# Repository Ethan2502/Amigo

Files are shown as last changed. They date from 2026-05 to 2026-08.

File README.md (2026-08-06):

# Amigo

A desk companion cube that takes over the things you unlock your phone for, so you have no reason to pick it up.

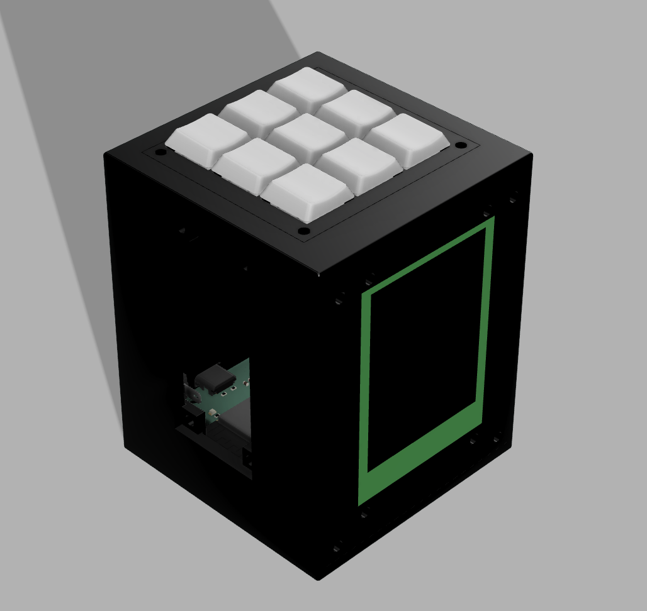
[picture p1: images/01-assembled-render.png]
Amigo assembled


## Why I made it

This is my project that I got an idea for when my phone's alarm went off. I always tend to use my phone a little bit in bed when I wake up. I thought I needed my phone to wake me up but then I thought of a product that replaced all the "utility" items your phone could do but without the distractions. I used screentime apps before but they always make it in fingers reach to disable it. Amigo takes the other approach. Instead of locking the phone down, it takes over the jobs you unlock the phone for in the first place, so there is nothing to reach for.

Physically locking the phone away is something I want to add later. The current design does not do it.

## What it does

1. **Wakes you up.** Alarm clock, so your phone doesn't have to be the thing next to your bed.
2. **Keeps your phone down.** The alarm, timer, and display all live on the cube, so there is no reason to unlock your phone for any of them.
3. **Utility stuff.** Timers, stopwatch, and the other simple things you'd normally pull your phone out for.
4. **Desk toy.** Displays pictures on a slide deck while you work.
5. **Classroom toy.** Small kids in elementary school can use it to develop cognitive function with memory games or reaction time tests. It can teach them things through games where they answer questions using the keypad as arrows or other controls to move, fight, and so on. It's a lot cheaper than buying a brand new computer or phone, so it's a budget friendly classroom toy.

## How it works

Amigo is two PCBs and a 3D printed case.

The **main board** carries an ESP32-S3-WROOM-1, a TP4056 LiPo charger, an AP2112K 3.3 V LDO, and headers for the display, the audio amp, the power switch, and the button matrix. It runs off a single-cell LiPo and charges over USB-C.

The **3x3 button matrix board** is a separate PCB with nine Kailh Choc hotswap switches and nine 1N4148W diodes in a standard row/column matrix, so nine keys read over six GPIO. It connects to the main board through an 8-pin ribbon header.

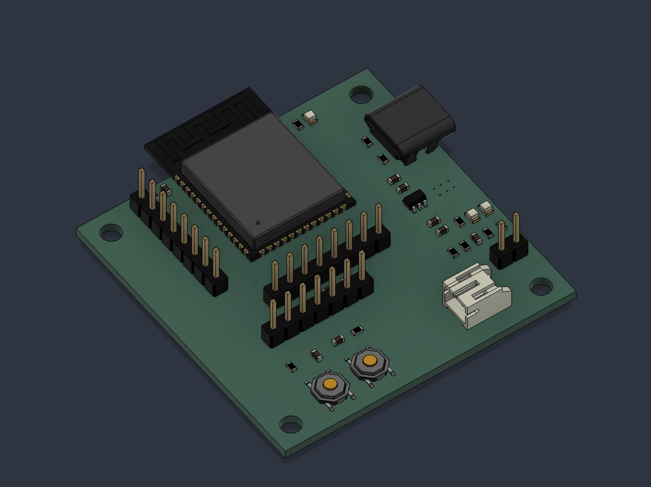
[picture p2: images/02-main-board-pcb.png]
Main board PCB render


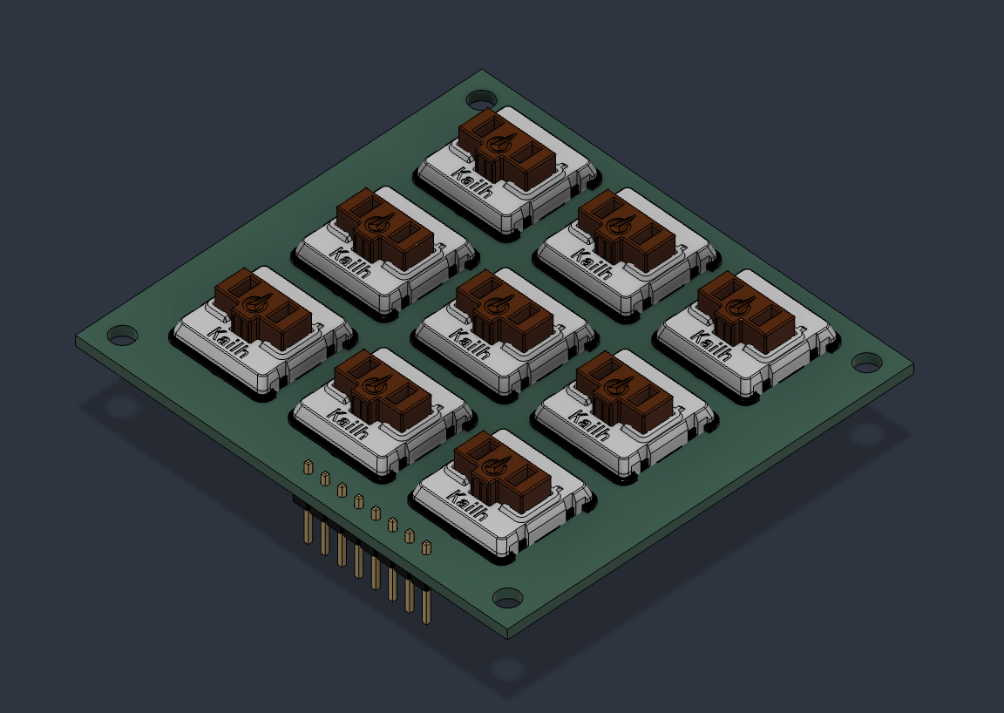
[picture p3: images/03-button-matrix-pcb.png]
Button matrix PCB render


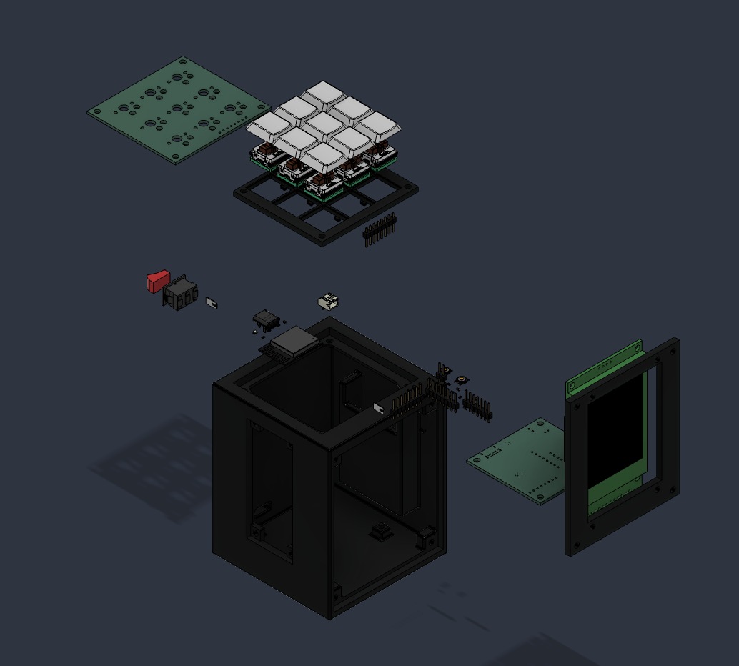
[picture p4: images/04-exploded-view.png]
Exploded View


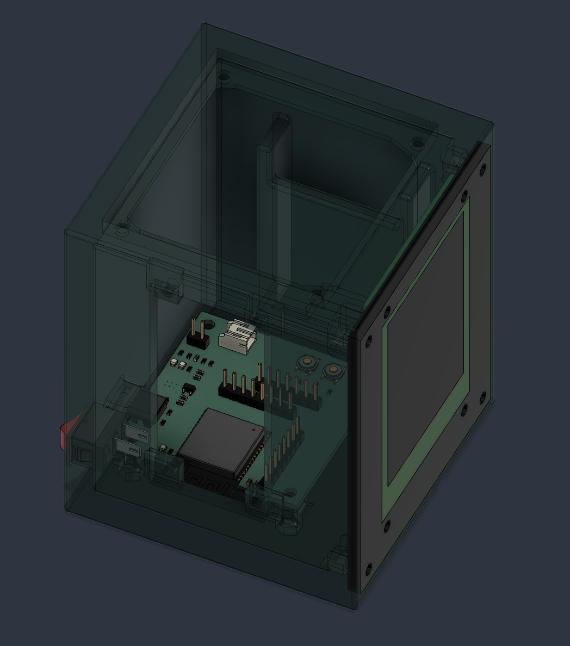
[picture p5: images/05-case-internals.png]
Case Internals


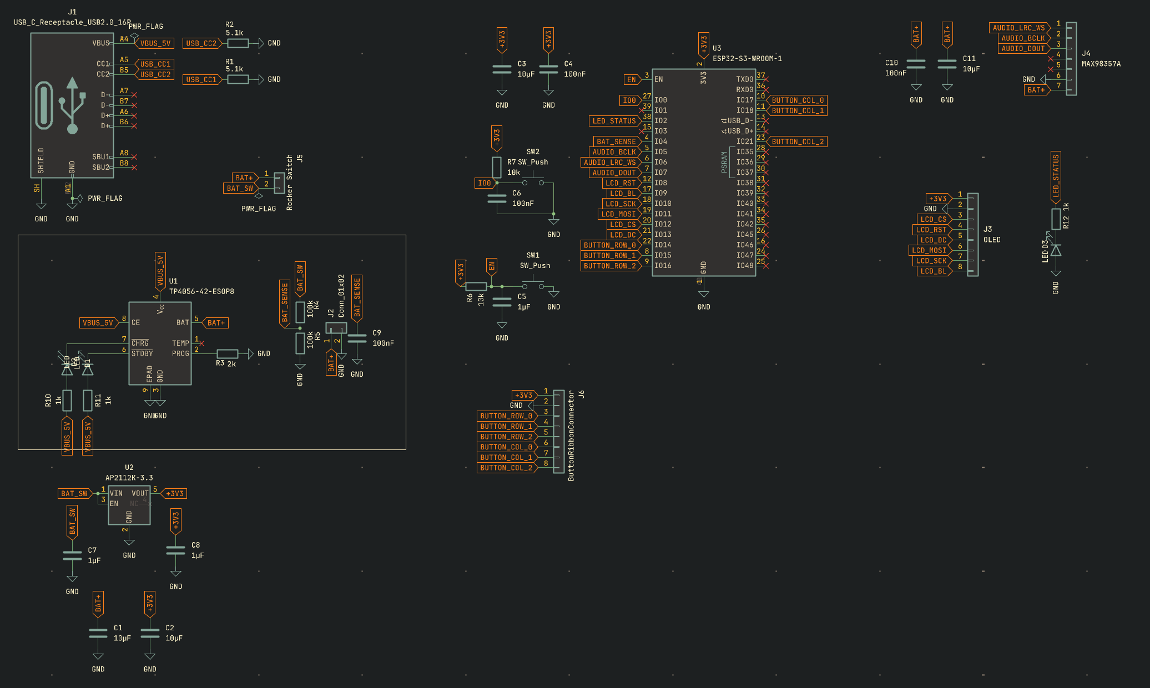
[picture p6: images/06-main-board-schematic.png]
Main Schematic


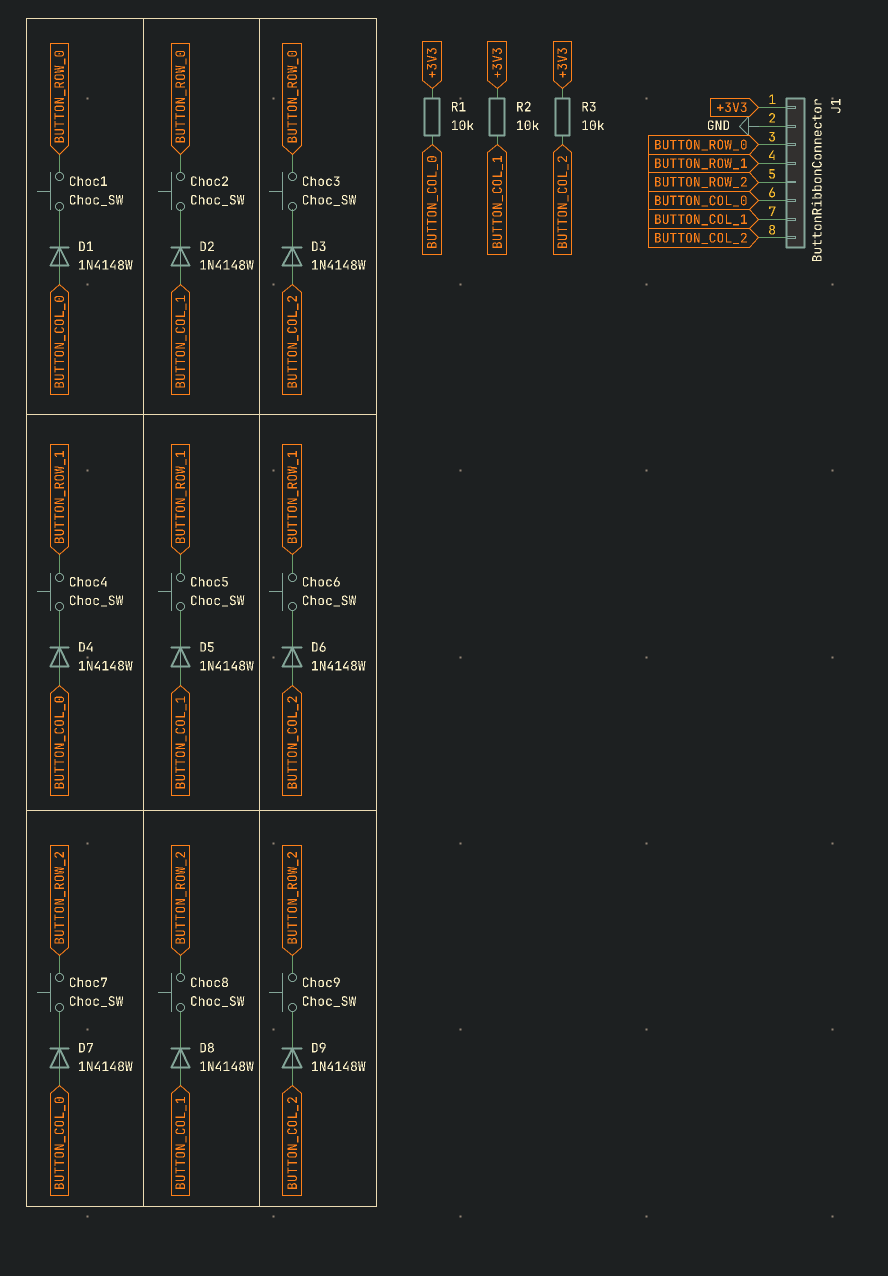
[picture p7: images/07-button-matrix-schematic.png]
Buttons Schematic


## Repo layout

```
hardware/
  main-board/          KiCad project for the ESP32-S3 main board
    production/        gerbers, BOM, pick-and-place files
  button-matrix/       KiCad project for the 3x3 switch board
    libs/              Keebio-Parts footprint library (third party, see credits)
    production/
cad/
  amigo.f3z            Fusion 360 Archive file for multi-component assemblies
  step/                STEP exports
  stl/                 printable parts
docs/                  assembly instructions
firmware/              (in progress)
images/                renders and photos
bom.csv                full bill of materials
```

## Assembly

### 1. Order the PCBs

Send `hardware/main-board/production/gerbers.zip` and `hardware/button-matrix/production/gerbers.zip` to your fab house. Both are 2-layer, 1.6 mm.

You can use PCBA to save time on soldering. If you don't it will be harder and you may or may not have to make a stencil. I ordered PCBA

### 2. Print the case

| Part | File | Notes |
| --- | --- | --- |
| Case | `cad/stl/case.stl` | Needs supports |
| Button cover | `cad/stl/button-cover.stl` | 10% Gyroid |
| Display mount | `cad/stl/display-mount.stl` | 10% Gyroid |
| Keycaps | `cad/stl/keycaps.stl` | x9 10% Gyroid |

Settings I used:
1. Gyroid Infill at 10%
2. Supports only on the case
3. The rest I used bambu slicer and their default settings for PLA

### 3. Solder the main board

If you ordered PCBA then skip. 

Use solder paste, wick, and flux to do solder. I believe using a stencil will make applying solder paste easier but I ordered PCBA. Solder all the parts on to it and also
don’t forget things like key caps for the buttons. Refer to Ki Cad files as
instructions for each cap or resistor and anything else you may need. 

Also the ESP board and the TP4056 should probably be soldered first because they are the most finicky. The TP4056 also has a thermal pad underneath. I suggest soldering all the passives like capacitators and resistors last.

### 4. Solder the button matrix

When you solder the button matrix it is important to make sure your diodes are the right direction. Normally when assmbling things I find it easier to have the file open whether it be a CAD or a PCB design. This way it is concrete in exactly what direction you planned for it earlier. Also don't forget keycaps while soldering.

### 5. Wire the modules

Again you can pull up the file to see which way the order is for the pin connectors. You can then work through it wire by wire by counting. This is the most concrete way to do it withought messing up. To be extra secure you can use some hot glue and secure the connection. 

### 6. Assemble the Cube

Use M3 screws and nuts to screw everything in. There should be a hole for each screw.

### 7. Flash the Firmware

Once firmware is written you can flash it. I have not written it yet I will update it later.

## Bill of Materials

Prices are per-unit at the quantity needed to build one Amigo. Several LCSC parts have minimum order quantities well above what the board uses (the 0603 passives ship in reels of 50 or 100), so the actual amount you spend at checkout will be higher than the totals below.

The main board was ordered as PCBA, so the surface-mount parts in the first table were supplied to the assembler rather than hand-soldered. The button matrix board was ordered bare and assembled by hand.

### Main board

| Ref | Part | Qty | Unit | Total | Link |
| --- | --- | --- | --- | --- | --- |
| U3 | ESP32-S3-WROOM-1-N16R8 | 1 | $5.16 | $5.16 | [C2913202](https://www.lcsc.com/product-detail/C2913202.html) |
| U1 | TP4056-42-ESOP8 LiPo charger (ESOP-8) | 1 | $0.19 | $0.19 | [C16581](https://www.lcsc.com/product-detail/C16581.html) |
| U2 | AP2112K-3.3TRG1 LDO (SOT-23-5) | 1 | $0.11 | $0.11 | [C23380830](https://www.lcsc.com/product-detail/C23380830.html) |
| J1 | USB4085-GF-A USB-C receptacle | 1 | $1.42 | $1.42 | [C7095263](https://www.lcsc.com/product-detail/C7095263.html) |
| J2 | S2B-PH-K-S-GW JST PH 2-pin, right angle | 1 | $0.18 | $0.18 | [C157932](https://www.lcsc.com/product-detail/C157932.html) |
| J3 | PPTC081LFBN-RC female header 1x08 2.54 mm (display) | 1 | $1.54 | $1.54 | [C3320851](https://www.lcsc.com/product-detail/C3320851.html) |
| J4 | PPTC071LFBN-RC female header 1x07 2.54 mm (audio amp) | 1 | $0.79 | $0.79 | [C5342086](https://www.lcsc.com/product-detail/C5342086.html) |
| J5 | PRPC002SAAN-RC pin header 1x02 2.54 mm (power switch) | 1 | $0.09 | $0.09 | [C3346540](https://www.lcsc.com/product-detail/C3346540.html) |
| J6 | PPTC081LFBN-RC female header 1x08 2.54 mm (button ribbon) | 1 | $1.54 | $1.54 | [C3320851](https://www.lcsc.com/product-detail/C3320851.html) |
| SW1, SW2 | TL3342F260QG tactile switch | 2 | $1.15 | $2.29 | [C2886894](https://www.lcsc.com/product-detail/C2886894.html) |
| D1 | YLED0805G green LED, 0805 | 1 | $0.01 | $0.01 | [C25170728](https://www.lcsc.com/product-detail/C25170728.html) |
| D2 | YLED0805B blue LED, 0805 | 1 | $0.01 | $0.01 | [C19273154](https://www.lcsc.com/product-detail/C19273154.html) |
| D3 | YLED0805R red LED, 0805 | 1 | $0.01 | $0.01 | [C19171391](https://www.lcsc.com/product-detail/C19171391.html) |
| C1, C2, C3, C11 | 10 µF 25 V X5R, 0603 | 4 | $0.48 | $1.92 | [C344022](https://www.lcsc.com/product-detail/C344022.html) |
| C4, C6, C9, C10 | 100 nF 50 V X7R, 0603 | 4 | $0.02 | $0.08 | [C14663](https://www.lcsc.com/product-detail/C14663.html) |
| C5, C7, C8 | 1 µF 25 V X7R, 0603 | 3 | $0.02 | $0.07 | [C29936](https://www.lcsc.com/product-detail/C29936.html) |
| R1, R2 | 5.1 kΩ 1%, 0603 | 2 | $0.01 | $0.01 | [C105580](https://www.lcsc.com/product-detail/C105580.html) |
| R3 | 2 kΩ 5%, 0603 | 1 | $0.01 | $0.01 | [C105581](https://www.lcsc.com/product-detail/C105581.html) |
| R4, R5 | 100 kΩ 1%, 0603 | 2 | $0.01 | $0.01 | [C14675](https://www.lcsc.com/product-detail/C14675.html) |
| R6, R7 | 10 kΩ 1%, 0603 | 2 | $0.01 | $0.01 | [C98220](https://www.lcsc.com/product-detail/C98220.html) |
| R10, R11, R12 | 1 kΩ 1%, 0603 | 3 | $0.01 | $0.02 | [C22548](https://www.lcsc.com/product-detail/C22548.html) |
| | **Main board subtotal** | | | **$15.47** | |

### Button matrix board

| Ref | Part | Qty | Unit | Total | Link |
| --- | --- | --- | --- | --- | --- |
| CHOC1-CHOC9 | Kailh Choc low profile hotswap socket | 9 | $0.78 | $7.02 | [Amazon](https://www.amazon.com/Mechkeeb-Kailh-Low-Hot-swappable-Socket/dp/B0BS3L174L) |
| | Kailh Choc low profile keyswitch | 9 | $1.92 | $17.28 | [Amazon](https://www.amazon.com/KAILH-Official-Chocolate-Mechanical-Keyboard/dp/B0B3MNBPSP) |
| D1-D9 | 1N4148W diode, SOD-123 | 9 | $0.01 | $0.08 | [C908248](https://www.lcsc.com/product-detail/C908248.html) |
| J1 | Header 1x08 2.54 mm (ribbon to main board) | 1 | $1.54 | $1.54 | [C3320851](https://www.lcsc.com/product-detail/C3320851.html) |
| R1, R2, R3 | 10 kΩ 1%, 0603 | 3 | $0.01 | $0.02 | [C98220](https://www.lcsc.com/product-detail/C98220.html) |
| | **Button matrix subtotal** | | | **$25.94** | |

Keycaps are 3D printed from `cad/stl/keycaps.stl`, so there is nothing to buy for them.

### Off-board parts

| Part | Qty | Unit | Total | Link |
| --- | --- | --- | --- | --- |
| HiLetgo 2.8 in ILI9341 SPI display, 240x320 | 1 | $16.39 | $16.39 | [Amazon](https://www.amazon.com/HiLetgo-240X320-Resolution-Display-ILI9341/dp/B073R7BH1B) |
| MAX98357A I2S audio amp breakout | 1 | $6.88 | $6.88 | [Amazon](https://www.amazon.com/MAX98357-MAX98357A-Amplifier-Interface-Raspberry/dp/B0DPJRLMDJ) |
| CQRobot speaker, JST-PH 2.0 mm interface | 1 | $7.99 | $7.99 | [Amazon](https://www.amazon.com/CQRobot-JST-PH2-0-Interface-Electronic-Projects/dp/B0738NLFTG) |
| EEMB 1100 mAh single-cell LiPo, JST connector | 1 | $6.15 | $6.15 | [Amazon](https://www.amazon.com/EEMB-1100mAh-Battery-Rechargeable-Connector/dp/B08VRYS8FT) |
| Rocker power switch | 1 | $1.35 | $1.35 | [AliExpress](https://www.aliexpress.us/item/3256812208202705.html) |
| Jumper wires, board-to-board ribbon link | 1 | $6.98 | $6.98 | [Amazon](https://www.amazon.com/Elegoo-EL-CP-004-Multicolored-Breadboard-arduino/dp/B01EV70C78) |
| PLA filament for case, button cover, display mount, keycaps | 1 | $20.00 | $20.00 | [Polymaker](https://shop.polymaker.com/products/polymaker-pla-pro?variant=41550910652473) |
| M3 screws and nuts pack of 100 | 1 | $15.30 | $15.30 | [McMaster](https://www.mcmaster.com/products/screws/socket-head-screws-2~/steel-socket-head-screws~~/?s=m3+screws) |
| PCB fabrication: main board PCBA and button matrix bare PCB | 1 | $50.65 | $50.65 | [JLCPCB](https://jlcpcb.com/) |
| | | | **$131.69 plus fasteners** | |

The Amazon parts ship in fixed pack sizes rather than the exact count the build uses. The Unit column is the per-item price and the Total is what one Amigo consumes, so your checkout total will be higher.

### Total

**$173.10 plus fasteners** to build one Amigo: $15.47 for the main board, $25.94 for the button matrix, and $116.39 in off-board parts and fabrication. Fabrication is the single largest line at $50.65.

## Tools used

Not part of the build, listed for anyone reproducing it.

| Tool | Link |
| --- | --- |
| Soldering iron | [Amazon](https://www.amazon.com/Wonderway-Soldering-Electronics-CELLPHONE-Repairing/dp/B0BLSJQPR6) |
| Desoldering pump | [Amazon](https://www.amazon.com/Lesnow-Desoldering-Electronics-Disassemble-Electrical/dp/B0F8BJPC9Y) |
| Multimeter | [Amazon](https://www.amazon.com/ANENG-Multimeter-Resistance-Continuity-Automotive/dp/B0BYD32JZV) |

## Firmware

Not written yet. The plan is firmware that lets people program the device, download or make games, and customize it for their needs, with over-the-wifi updates so the software keeps getting better.

## Credits

The `hardware/button-matrix/libs/Keebio-Parts.pretty-master` footprint library is Keebio's, used under its own license for the Kailh Choc footprints. Everything else in this repo is my own work.

## What I learned

I used a bunch of stuff on this project for the first time, like KiCad to make my PCBs. I realize how hard it is to actually verify if some PCB works before you order it. I guess it is because I didn't have a breadboard kit. Some of the most memorable things I learned about electronic design is things like not forgetting a fuse or remembering to add EN and Boot switches. I also learned to try and plan the actual product out before because I wanted motors to drive it but I didn't account for any sizing constraints and it turned out to be to out of reach for a first project.

I really enjoyed putting everything together at the end in Fusion with the actual CAD of the PCB. My least faveorite part was actually ordering everything because who knew things cost money! I didn't notice but my amazon cart added up quick and I made a switch to ali express and was able to save some money. JLC was also really annoying one day where it kept rejecting my files and it didn't work and I had to restart the entire process from scratch to try and debug it. Another thing I learned while ordering was the company LCSC sells parts but it takes time to quote it. They sent me an email but I didn't check it so I forgot to actually order it! Overall I am excited to assmble this thing I have been working on for a long time.

---

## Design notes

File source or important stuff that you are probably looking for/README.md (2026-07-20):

Amigo

This is my project that I got an idea for when my phone's alarm went off. I always tend to use my phone a little bit in bed when I wake up. I thought I needed my phone to wake me up but then I thought of a product that replaced all the "utility" items your phone could do but without the distractions. I also thought to take this a step further and make a product that could block screentime on your phone. 

Why does it need to physically block screentime and not an app? I used apps before but they always make it in fingers reach to disable it. So this product is a phone buddy to help you stay focused!

This Amigo can also be a cool desk toy when you're working by displaying pictures on a "slide deck". 

So in total this Amigo can:
1. Wake you up
2. Block your phone
3. Set timers, stopwatches, and other simple stuff your phone can do.
4. I was also thinking that small kids in elementary school can also try this out as a way to develop more coginitve function like memory games or reaction time things. It can teach them stuff by making a a game where they can answer questions using the keypad as arrows or other controls to move, fight, etc. The benefit of this is the product is a lot cheaper too than buying a brand new computer or phone. So it's a budget friendly calssroom toy!

I used a bunch of stuff on this project for the first time like Ki Cad to make my pcbs. 
In my pcbs I have an ESP with all the stuff connected like speakers, screens, charging, and some other stuff.

I have another 3x3 button matrix pcb connected to my main board with jumper cables. 

For the software I am planning to make some firmware so people can also program, download/make games, and customize it for their needs.
I want it to have a over the wifi updates so it can get better and better software.

Very excited to be in this stage to start building it.

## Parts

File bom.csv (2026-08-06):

Board | Reference | Part | LCSC Part # | Quantity | Unit Price | Total Price | Link
Main board | U3 | ESP32-S3-WROOM-1-N16R8 | C2913202 | 1 | $5.16 | $5.16 | https://www.lcsc.com/product-detail/C2913202.html
Main board | U1 | TP4056-42-ESOP8 LiPo charger (ESOP-8) | C16581 | 1 | $0.19 | $0.19 | https://www.lcsc.com/product-detail/C16581.html
Main board | U2 | AP2112K-3.3TRG1 LDO (SOT-23-5) | C23380830 | 1 | $0.11 | $0.11 | https://www.lcsc.com/product-detail/C23380830.html
Main board | J1 | USB4085-GF-A USB-C receptacle | C7095263 | 1 | $1.42 | $1.42 | https://www.lcsc.com/product-detail/C7095263.html
Main board | J2 | S2B-PH-K-S-GW JST PH 2-pin right angle | C157932 | 1 | $0.18 | $0.18 | https://www.lcsc.com/product-detail/C157932.html
Main board | J3 | PPTC081LFBN-RC female header 1x08 2.54mm (display) | C3320851 | 1 | $1.54 | $1.54 | https://www.lcsc.com/product-detail/C3320851.html
Main board | J4 | PPTC071LFBN-RC female header 1x07 2.54mm (audio amp) | C5342086 | 1 | $0.79 | $0.79 | https://www.lcsc.com/product-detail/C5342086.html
Main board | J5 | PRPC002SAAN-RC pin header 1x02 2.54mm (power switch) | C3346540 | 1 | $0.09 | $0.09 | https://www.lcsc.com/product-detail/C3346540.html
Main board | J6 | PPTC081LFBN-RC female header 1x08 2.54mm (button ribbon) | C3320851 | 1 | $1.54 | $1.54 | https://www.lcsc.com/product-detail/C3320851.html
Main board | SW1, SW2 | TL3342F260QG tactile switch | C2886894 | 2 | $1.15 | $2.29 | https://www.lcsc.com/product-detail/C2886894.html
Main board | D1 | YLED0805G green LED 0805 | C25170728 | 1 | $0.01 | $0.01 | https://www.lcsc.com/product-detail/C25170728.html
Main board | D2 | YLED0805B blue LED 0805 | C19273154 | 1 | $0.01 | $0.01 | https://www.lcsc.com/product-detail/C19273154.html
Main board | D3 | YLED0805R red LED 0805 | C19171391 | 1 | $0.01 | $0.01 | https://www.lcsc.com/product-detail/C19171391.html
Main board | C1, C2, C3, C11 | 10uF 25V X5R 0603 capacitor | C344022 | 4 | $0.48 | $1.92 | https://www.lcsc.com/product-detail/C344022.html
Main board | C4, C6, C9, C10 | 100nF 50V X7R 0603 capacitor | C14663 | 4 | $0.02 | $0.08 | https://www.lcsc.com/product-detail/C14663.html
Main board | C5, C7, C8 | 1uF 25V X7R 0603 capacitor | C29936 | 3 | $0.02 | $0.07 | https://www.lcsc.com/product-detail/C29936.html
Main board | R1, R2 | 5.1k 1% 0603 resistor | C105580 | 2 | $0.01 | $0.01 | https://www.lcsc.com/product-detail/C105580.html
Main board | R3 | 2k 5% 0603 resistor | C105581 | 1 | $0.01 | $0.01 | https://www.lcsc.com/product-detail/C105581.html
Main board | R4, R5 | 100k 1% 0603 resistor | C14675 | 2 | $0.01 | $0.01 | https://www.lcsc.com/product-detail/C14675.html
Main board | R6, R7 | 10k 1% 0603 resistor | C98220 | 2 | $0.01 | $0.01 | https://www.lcsc.com/product-detail/C98220.html
Main board | R10, R11, R12 | 1k 1% 0603 resistor | C22548 | 3 | $0.01 | $0.02 | https://www.lcsc.com/product-detail/C22548.html
Button matrix | CHOC1-CHOC9 | Kailh Choc low profile hotswap socket |  | 9 | $0.78 | $7.02 | https://www.amazon.com/Mechkeeb-Kailh-Low-Hot-swappable-Socket/dp/B0BS3L174L
Button matrix |  | Kailh Choc low profile keyswitch |  | 9 | $1.92 | $17.28 | https://www.amazon.com/KAILH-Official-Chocolate-Mechanical-Keyboard/dp/B0B3MNBPSP
Button matrix | D1-D9 | 1N4148W diode SOD-123 | C908248 | 9 | $0.01 | $0.08 | https://www.lcsc.com/product-detail/C908248.html
Button matrix | J1 | Header 1x08 2.54mm (ribbon to main board) | C3320851 | 1 | $1.54 | $1.54 | https://www.lcsc.com/product-detail/C3320851.html
Button matrix | R1, R2, R3 | 10k 1% 0603 resistor | C98220 | 3 | $0.01 | $0.02 | https://www.lcsc.com/product-detail/C98220.html
Off-board |  | HiLetgo 2.8in ILI9341 240x320 SPI display module |  | 1 | $16.39 | $16.39 | https://www.amazon.com/HiLetgo-240X320-Resolution-Display-ILI9341/dp/B073R7BH1B
Off-board |  | MAX98357A I2S audio amp breakout |  | 1 | $6.88 | $6.88 | https://www.amazon.com/MAX98357-MAX98357A-Amplifier-Interface-Raspberry/dp/B0DPJRLMDJ
Off-board |  | CQRobot speaker JST-PH 2.0mm interface |  | 1 | $7.99 | $7.99 | https://www.amazon.com/CQRobot-JST-PH2-0-Interface-Electronic-Projects/dp/B0738NLFTG
Off-board |  | EEMB 1100mAh single-cell LiPo battery with JST connector |  | 1 | $6.15 | $6.15 | https://www.amazon.com/EEMB-1100mAh-Battery-Rechargeable-Connector/dp/B08VRYS8FT
Off-board |  | Rocker power switch |  | 1 | $1.35 | $1.35 | https://www.aliexpress.us/item/3256812208202705.html
Off-board |  | Jumper wires (board-to-board ribbon link) |  | 1 | $6.98 | $6.98 | https://www.amazon.com/Elegoo-EL-CP-004-Multicolored-Breadboard-arduino/dp/B01EV70C78
Off-board |  | PLA filament for case, button cover, display mount, keycaps |  | 1 | $20.00 | $20.00 | https://shop.polymaker.com/products/polymaker-pla-pro?variant=41550910652473
Off-board |  | M3 screws and nuts |  | 1 | $15.30 | $15.30 | https://www.mcmaster.com/products/screws/socket-head-screws-2~/steel-socket-head-screws~~/?s=m3+screws
Off-board |  | PCB fabrication: main board PCBA and button matrix bare PCB |  | 1 | $50.65 | $50.65 | https://jlcpcb.com/

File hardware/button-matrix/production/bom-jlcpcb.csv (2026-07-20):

Designator | Footprint | Quantity | Value | LCSC Part #
CHOC1, CHOC2, CHOC3, CHOC4, CHOC5, CHOC6, CHOC7, CHOC8, CHOC9 | SW_choc_v1+v2_HS_CPG135001S30_1u | 9 | Choc_SW
D1, D2, D3, D4, D5, D6, D7, D8, D9 | D_SOD-123 | 9 | 1N4148W
J1 | PinHeader_1x08_P2.54mm_Vertical | 1 | ButtonRibbonConnector
R1, R2, R3 | 0603 | 3 | 10k

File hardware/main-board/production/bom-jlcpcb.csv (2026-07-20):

Designator | Footprint | Quantity | Value | LCSC Part #
C1, C11, C2, C3 | 0603 | 4 | 10µF
C10, C4, C6, C9 | 0603 | 4 | 100nF
C5, C7, C8 | 0603 | 3 | 1µF
D1, D2, D3 | 0805 | 3 | LED
J1 | USB_C_Receptacle_GCT_USB4085 | 1 | USB_C_Receptacle_USB2.0_16P
J2 | JST_PH_S2B-PH-K_1x02_P2.00mm_Horizontal | 1 | Conn_01x02
J3 | PinHeader_1x08_P2.54mm_Vertical | 1 | OLED
J4 | PinHeader_1x07_P2.54mm_Vertical | 1 | MAX98357A
J5 | PinHeader_1x02_P2.54mm_Vertical | 1 | Rocker Switch
J6 | PinHeader_1x08_P2.54mm_Vertical | 1 | ButtonRibbonConnector
R1, R2 | 0603 | 2 | 5.1k
R10, R11, R12 | 0603 | 3 | 1k
R3 | 0603 | 1 | 2k
R4, R5 | 0603 | 2 | 100k
R6, R7 | 0603 | 2 | 10k
SW1, SW2 | SW_SPST_TL3342 | 2 | SW_Push
U1 | SOIC-8-1EP_3.9x4.9mm_P1.27mm_EP2.41x3.3mm_ThermalVias | 1 | TP4056-42-ESOP8
U2 | SOT-23-5 | 1 | AP2112K-3.3
U3 | ESP32-S3-WROOM-1 | 1 | ESP32-S3-WROOM-1

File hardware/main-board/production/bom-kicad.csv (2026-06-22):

Id | Designator | Footprint | Quantity | Designation | Supplier and ref
1 | C1, C2, C3, C11 | C_0603_1608Metric | 4 | 10µF
2 | C4, C6, C9, C10 | C_0603_1608Metric | 4 | 100nF
3 | C5, C7, C8 | C_0603_1608Metric | 3 | 1µF
4 | D1, D2, D3 | LED_0805_2012Metric | 3 | LED
5 | J1 | USB_C_Receptacle_GCT_USB4085 | 1 | USB_C_Receptacle_USB2.0_16P
6 | J2 | JST_PH_S2B-PH-K_1x02_P2.00mm_Horizontal | 1 | Conn_01x02
7 | J3 | PinHeader_1x08_P2.54mm_Vertical | 1 | OLED
8 | J4 | PinHeader_1x07_P2.54mm_Vertical | 1 | MAX98357A
9 | J5 | PinHeader_1x02_P2.54mm_Vertical | 1 | Rocker Switch
10 | J6 | PinHeader_1x08_P2.54mm_Vertical | 1 | ButtonRibbonConnector
11 | R1, R2 | R_0603_1608Metric | 2 | 5.1k
12 | R3 | R_0603_1608Metric | 1 | 2k
13 | R4, R5 | R_0603_1608Metric | 2 | 100k
14 | R6, R7 | R_0603_1608Metric | 2 | 10k
15 | R10, R11, R12 | R_0603_1608Metric | 3 | 1k
16 | SW1, SW2 | SW_SPST_TL3342 | 2 | SW_Push
17 | U1 | SOIC-8-1EP_3.9x4.9mm_P1.27mm_EP2.41x3.3mm_ThermalVias | 1 | TP4056-42-ESOP8
18 | U2 | SOT-23-5 | 1 | AP2112K-3.3
19 | U3 | ESP32-S3-WROOM-1 | 1 | ESP32-S3-WROOM-1

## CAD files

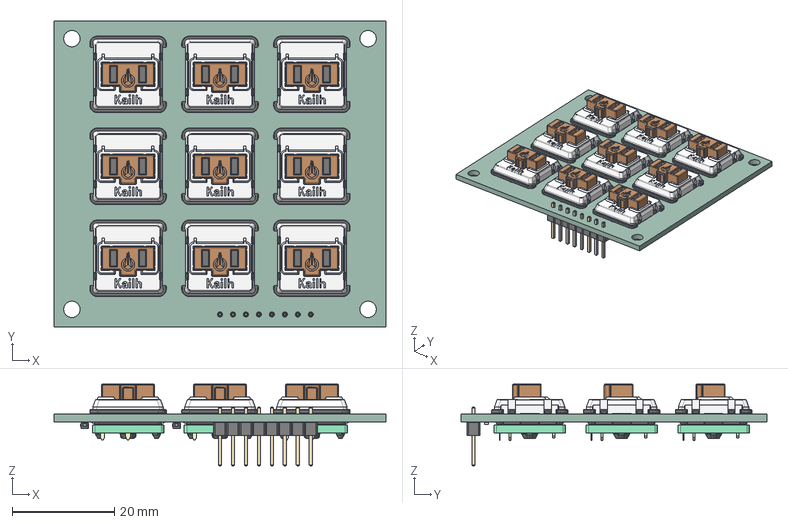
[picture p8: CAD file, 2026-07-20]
cad/step/main-board.step
65.0 x 60.0 x 16.0 mm
Kailh Choc Low Profile Switch x 9
D_SOD-123 x 9
PinHeader_1x08_P2.54mm_Vertical
R_0603_1608Metric x 3
ButtonMatrix3x3_PCB

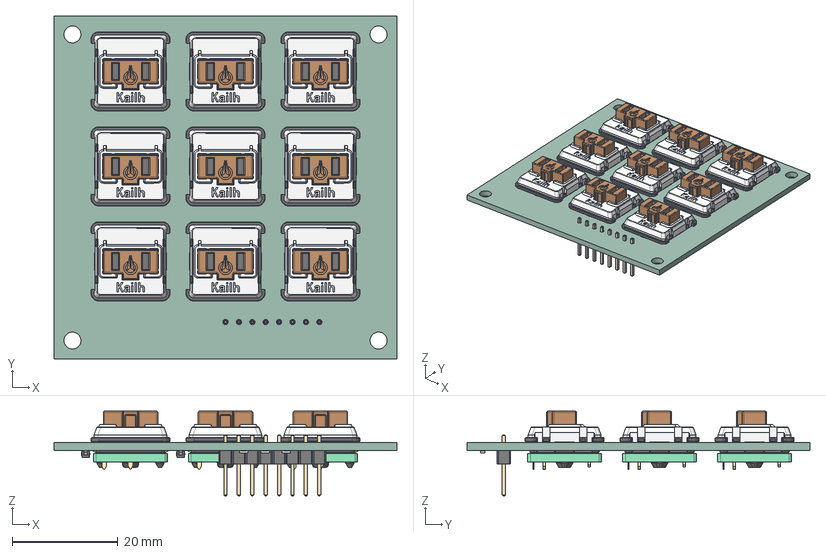
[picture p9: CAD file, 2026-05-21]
ButtonMatrix3x3/.step
65.0 x 65.0 x 16.0 mm
Kailh Choc Low Profile Switch x 9
D_SOD-123 x 9
PinHeader_1x08_P2.54mm_Vertical
R_0603_1608Metric x 3
ButtonMatrix3x3_PCB

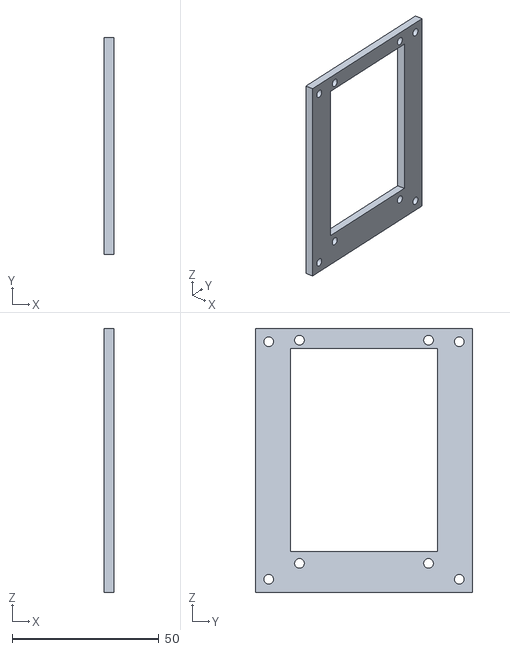
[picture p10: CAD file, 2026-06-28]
cad/stl/display-mount.stl
3.54 x 74.0 x 90.0

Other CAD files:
cad/step/button-matrix.step
cad/amigo.f3z

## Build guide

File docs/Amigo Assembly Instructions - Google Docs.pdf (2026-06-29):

# Assembly guide

# For Amigo

# Getting started

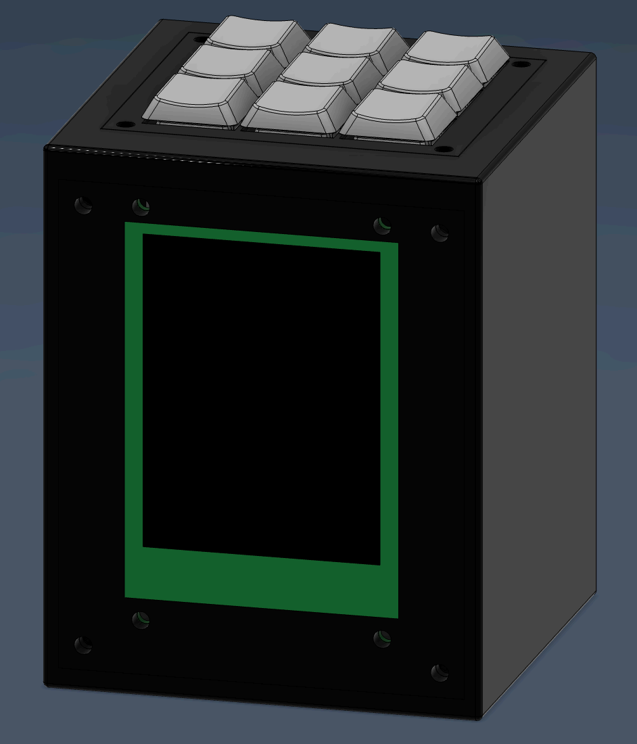
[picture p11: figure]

## INSTALLATION

# Step-by-step instructions

## Task 1

STEP 1

→ Once the PCBs arrive you need to SMD solder them.

→ Use solder paste, wick, and flux to do it. Solder all the parts on to it and also don’t forget things like key caps for the buttons. Refer to Ki Cad files as instructions for each cap or resistor and anything else you may need.

STEP 2

→ 3D print all the STLs from the CAD

→ Use the STLs or regenerate your own from the step file and send them to your printer.

STEP 3

→ Attach the PCBs to the case

→ Use M3 screws and nuts to secure it using the designated holes for that. The Main board goes into the big box and the buttons attach to the cover and base. Add the rocker switch here too press fit but hot glue or glue is optional.

STEP 4

→ Connect the buttons and main board

→ Using jumper wires plug the corresponding connector of both boards in.

STEP 5

→ Place key caps on top of the switches.

→ Push the 3D printed key caps onto the buttons.

STEP 6

→ Attach the case together and add battery

→ Screw in the rest of the case to secure everything together. Also use M3 screws and nuts. You can slot the battery in the corresponding slot and connect the JST cables.

STEP 7

→ Charge and Power on

→ Now you can plug it in, turn it on and start using it.

# Dependencies

## Summarize dependencies, and list the

dependencies and installation instructions.

## Dependency 01

→ You should have all the parts with you. You also need the necessary tools and materials to build it. Things like 3D printer, solder, multimeter, filament, etc.

## Dependency 02

→ You should have some comfortabilty with problem solving. The soldering section may be troublesome because of things like messy soldering or stuff like that which has to be debugged with a multimeter.

# Shopping List

Wires (https://www.amazon.com/Elegoo-EL-CP-004-Multicolored-Breadboard-arduino/dp/B01EV70C78?nsdOptOutParam=true)

Hotswap Mechanism (https://www.amazon.com/Mechkeeb-Kailh-Low-Hot-swappable-Socket/dp/B0BS3L174L?sr=8-4)

Switches (https://www.amazon.com/KAILH-Official-Chocolate-Mechanical-Keyboard/dp/B0B3MNBPSP?sr=8-11)

Speaker (https://www.amazon.com/CQRobot-JST-PH2-0-Interface-Electronic-Projects/dp/B0738NLFTG?sr=8-4)

Battery (https://www.amazon.com/EEMB-1100mAh-Battery-Rechargeable-Connector/dp/B08VRYS8FT?sr=8-10)

OLED (https://www.amazon.com/HiLetgo-240X320-Resolution-Display-ILI9341/dp/B073R7BH1B?nsdOptOutParam=true)

Solder Wick and Flux (https://www.amazon.com/Lesnow-Desoldering-Electronics-Disassemble-Electrical/dp/B0F8BJPC9Y?sr=8-6)

Multimeter (https://www.amazon.com/ANENG-Multimeter-Resistance-Continuity-Automotive/dp/B0BYD32JZV?sr=8-6)

Solder Paste (https://www.amazon.com/Wonderway-Soldering-Electronics-CELLPHONE-Repairing/dp/B0BLSJQPR6?sr=8-6)

PCBs from JLCPCB (https://cart.jlcpcb.com/shopcart/cart)

LCSC Shopping Cart (https://www.lcsc.com/cart?lcsc_vid=QFlXX1EHEVUKXlcDTgINBAdWQVdbUFUAQARdAwEDRVcxVlNeRlBXU1JRQ1JdXjtW)

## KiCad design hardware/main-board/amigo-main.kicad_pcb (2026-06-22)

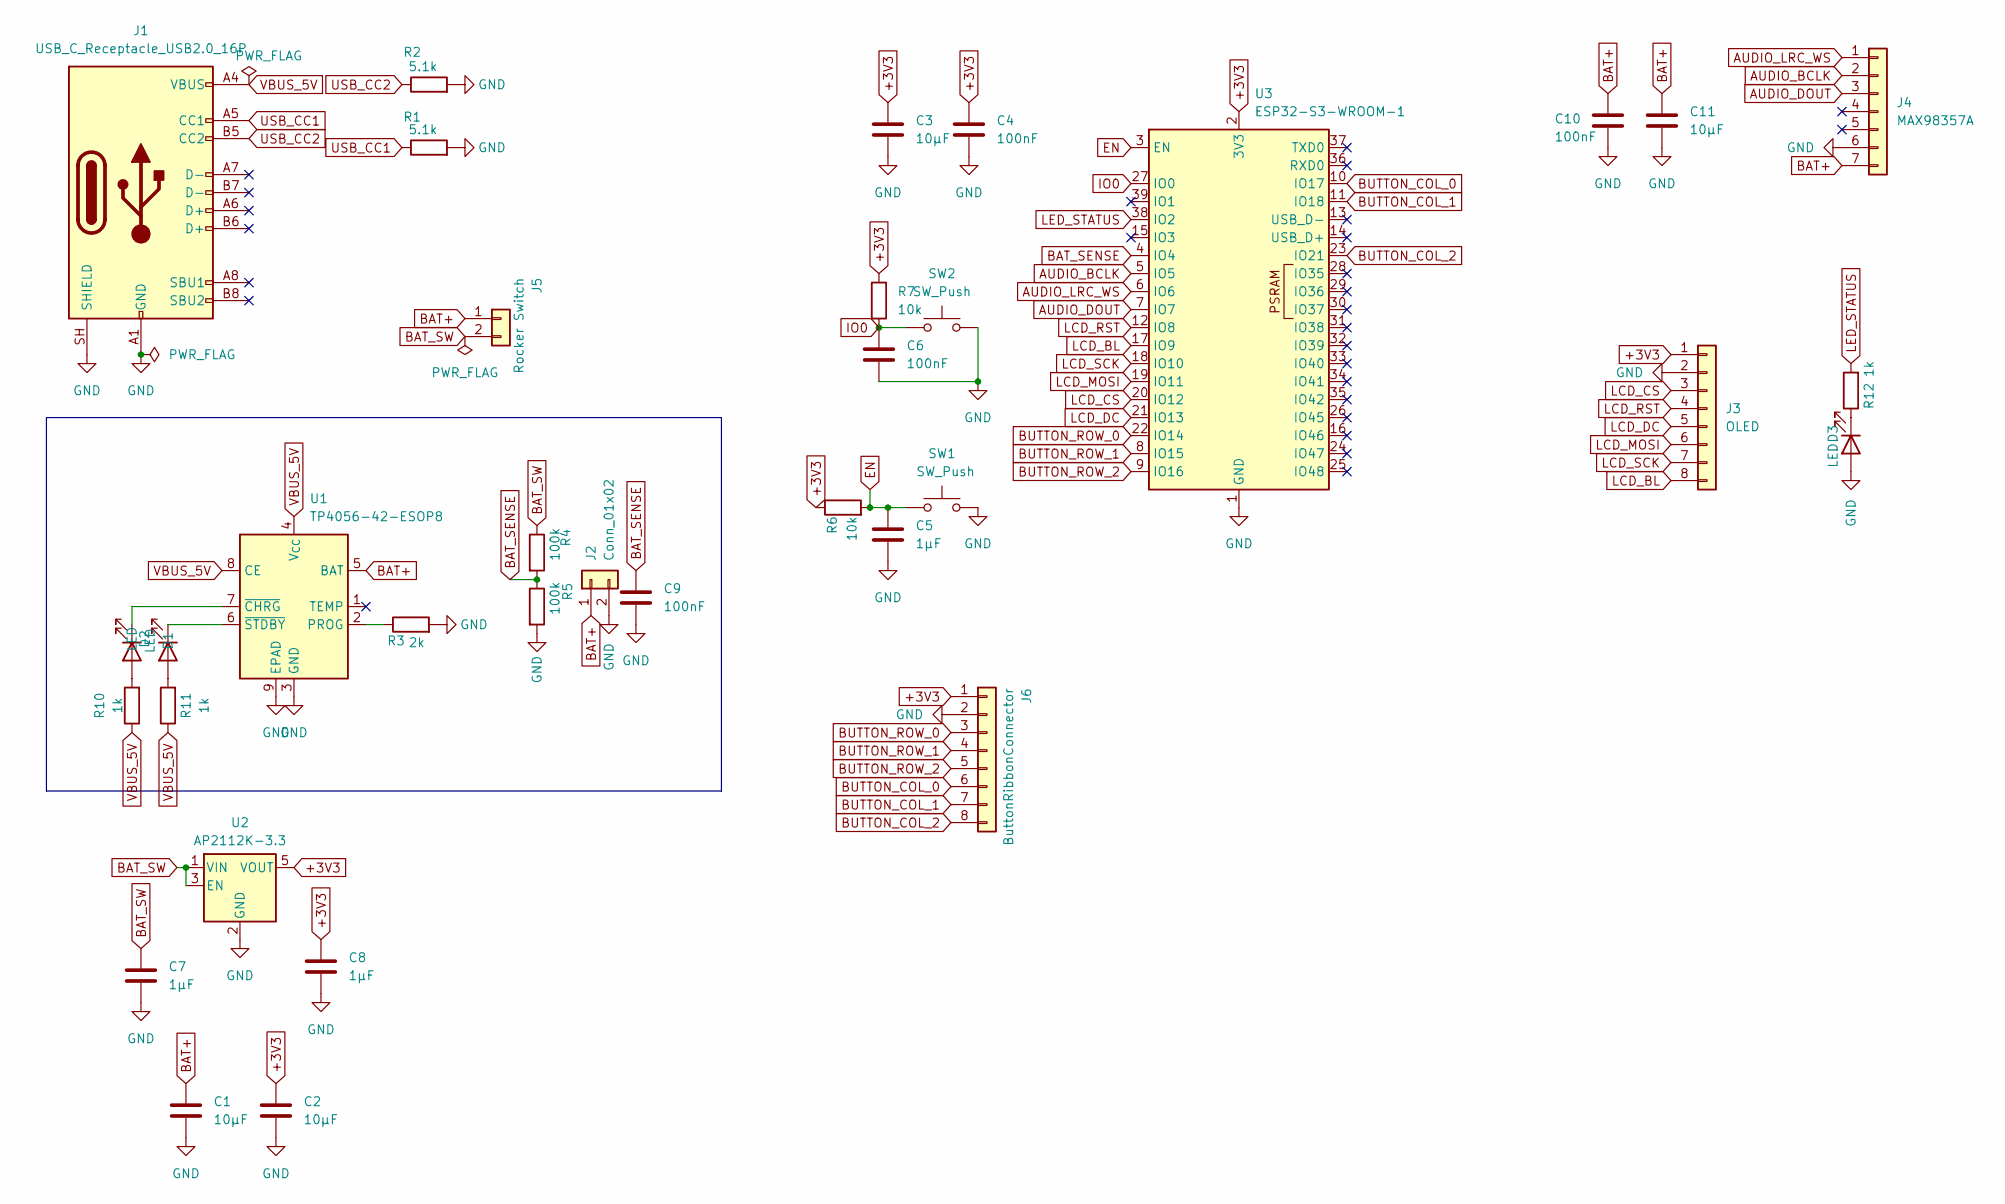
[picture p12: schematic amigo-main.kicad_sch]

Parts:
C1, C2, C3, C11: 10µF; C_0603_1608Metric
C4, C6, C9, C10: 100nF; C_0603_1608Metric
C5, C7, C8: 1µF; C_0603_1608Metric
D1, D2, D3: LED; LED_0805_2012Metric
J1: USB_C_Receptacle_USB2.0_16P; USB_C_Receptacle_GCT_USB4085
J2: Conn_01x02; JST_PH_S2B-PH-K_1x02_P2.00mm_Horizontal
J3: OLED; PinHeader_1x08_P2.54mm_Vertical
J4: MAX98357A; PinHeader_1x07_P2.54mm_Vertical
J5: Rocker Switch; PinHeader_1x02_P2.54mm_Vertical
J6: ButtonRibbonConnector; PinHeader_1x08_P2.54mm_Vertical
R1, R2: 5.1k; R_0603_1608Metric
R3: 2k; R_0603_1608Metric
R4, R5: 100k; R_0603_1608Metric
R6, R7: 10k; R_0603_1608Metric
R10, R11, R12: 1k; R_0603_1608Metric
SW1, SW2: SW_Push; SW_SPST_TL3342
U1: TP4056-42-ESOP8; SOIC-8-1EP_3.9x4.9mm_P1.27mm_EP2.41x3.3mm_ThermalVias
U2: AP2112K-3.3; SOT-23-5
U3: ESP32-S3-WROOM-1

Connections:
+3V3: C2.1, C3.1, C4.1, C8.1, J3.1, J6.1, R6.1, R7.1, U2.5 (VOUT), U3.2 (3V3)
AUDIO_BCLK: J4.2, U3.5 (IO5)
AUDIO_DOUT: J4.3, U3.7 (IO7)
AUDIO_LRC_WS: J4.1, U3.6 (IO6)
BAT+: C1.1, C10.1, C11.1, J2.1, J4.7, J5.1, U1.5 (BAT)
BAT_SENSE: C9.1, R4.2, R5.1, U3.4 (IO4)
BAT_SW: C7.1, J5.2, R4.1, U2.1 (VIN), U2.3 (EN)
BUTTON_COL_0: J6.6, U3.10 (IO17)
BUTTON_COL_1: J6.7, U3.11 (IO18)
BUTTON_COL_2: J6.8, U3.23 (IO21)
BUTTON_ROW_0: J6.3, U3.22 (IO14)
BUTTON_ROW_1: J6.4, U3.8 (IO15)
BUTTON_ROW_2: J6.5, U3.9 (IO16)
EN: C5.1, R6.2, SW1.1, U3.3 (EN)
GND: C1.2, C2.2, C3.2, C4.2, C5.2, C6.2, C7.2, C8.2, C9.2, C10.2, C11.2, D3.2 (A), J1.A1 (GND), J1.A12 (GND), J1.B1 (GND), J1.B12 (GND), J1.SH (SHIELD), J2.2, J3.2, J4.6, J6.2, R1.2, R2.2, R3.2, R5.2, SW1.2, SW2.2, U1.3 (GND), U1.9 (EPAD), U2.2 (GND), U3.1 (GND), U3.40 (GND), U3.41 (GND)
IO0: C6.1, R7.2, SW2.1, U3.27 (IO0)
LCD_BL: J3.8, U3.17 (IO9)
LCD_CS: J3.3, U3.20 (IO12)
LCD_DC: J3.5, U3.21 (IO13)
LCD_MOSI: J3.6, U3.19 (IO11)
LCD_RST: J3.4, U3.12 (IO8)
LCD_SCK: J3.7, U3.18 (IO10)
LED_STATUS: R12.2, U3.38 (IO2)
unnamed: D1.2 (A), R10.2
unnamed: D1.1 (K), U1.7 (~CHRG)
unnamed: D2.2 (A), R11.2
unnamed: D2.1 (K), U1.6 (~STDBY)
unnamed: D3.1 (K), R12.1
unnamed: R3.1, U1.2 (PROG)
USB_CC1: J1.A5 (CC1), R1.1
USB_CC2: J1.B5 (CC2), R2.1
VBUS_5V: J1.A4 (VBUS), J1.A9 (VBUS), J1.B4 (VBUS), J1.B9 (VBUS), R10.1, R11.1, U1.4 (V_{CC}), U1.8 (CE)

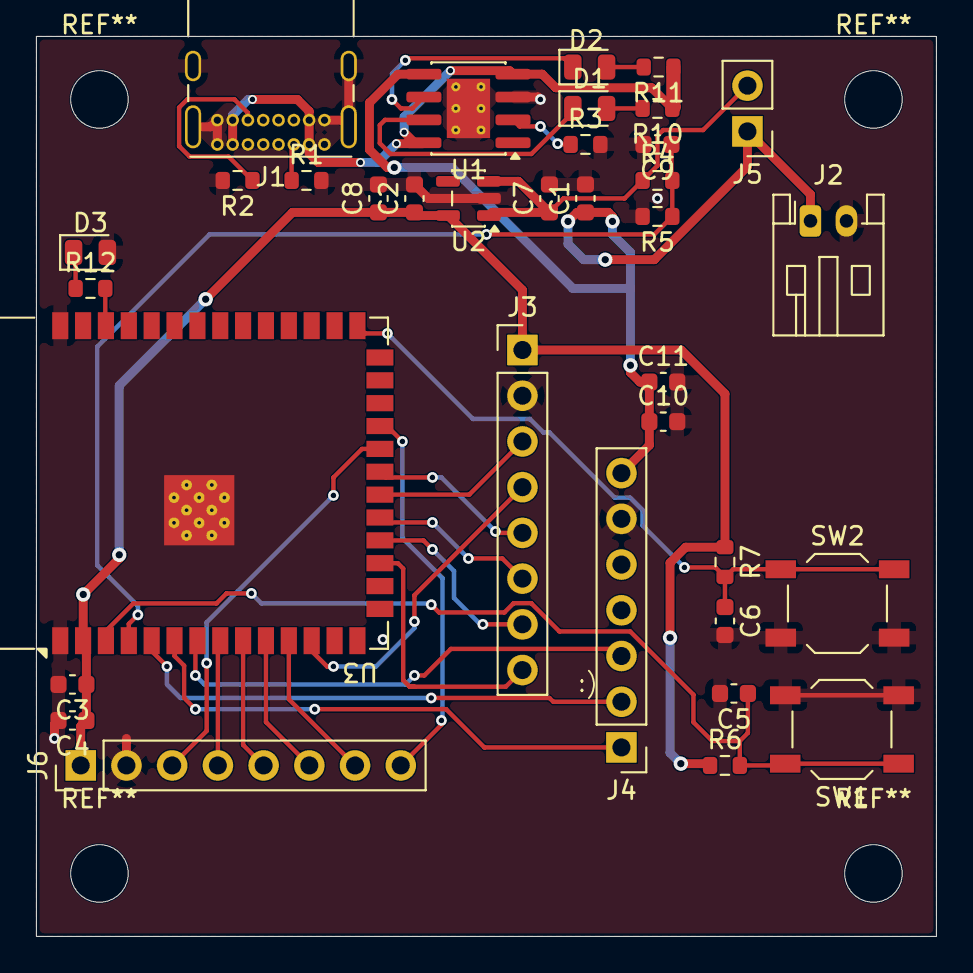
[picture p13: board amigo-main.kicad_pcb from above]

Board: 2 copper layers, 50.0 x 50.0 mm, 35 parts (0 on the bottom side), 32 nets.

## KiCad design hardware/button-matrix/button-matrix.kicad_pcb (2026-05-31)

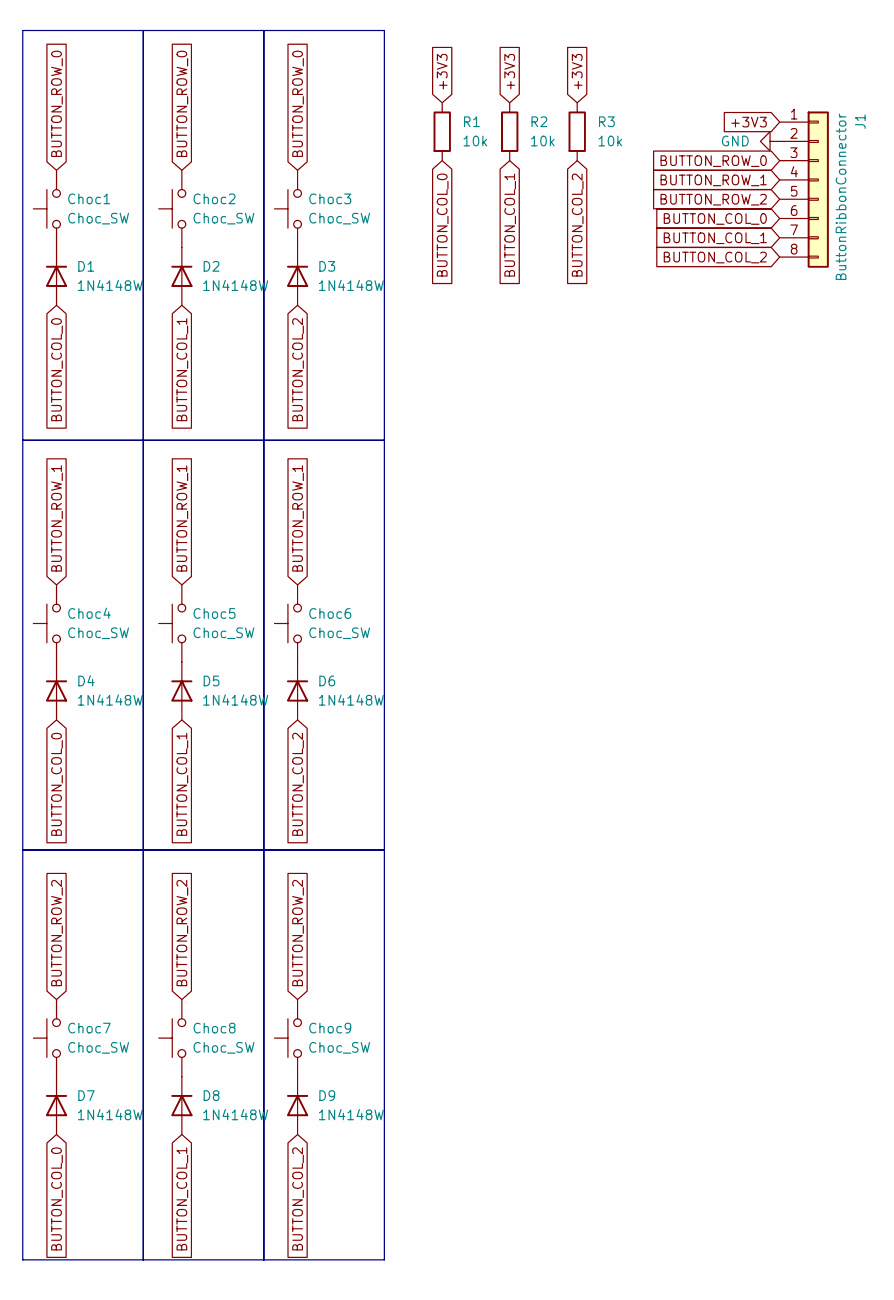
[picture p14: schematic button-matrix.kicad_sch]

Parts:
Choc1, Choc2, Choc3, Choc4, Choc5, Choc6, Choc7, Choc8, Choc9: Choc_SW; SW_choc_v1+v2_HS_CPG135001S30_1u
D1, D2, D3, D4, D5, D6, D7, D8, D9: 1N4148W; D_SOD-123
J1: ButtonRibbonConnector; PinHeader_1x08_P2.54mm_Vertical
R1, R2, R3: 10k; R_0603_1608Metric

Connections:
+3V3: J1.1, R1.1, R2.1, R3.1
BUTTON_COL_0: D1.2 (A), D4.2 (A), D7.2 (A), J1.6, R1.2
BUTTON_COL_1: D2.2 (A), D5.2 (A), D8.2 (A), J1.7, R2.2
BUTTON_COL_2: D3.2 (A), D6.2 (A), D9.2 (A), J1.8, R3.2
BUTTON_ROW_0: Choc1.2, Choc2.2, Choc3.2, J1.3
BUTTON_ROW_1: Choc4.2, Choc5.2, Choc6.2, J1.4
BUTTON_ROW_2: Choc7.2, Choc8.2, Choc9.2, J1.5
GND: J1.2
unnamed: Choc1.1, D1.1 (K)
unnamed: Choc2.1, D2.1 (K)
unnamed: Choc3.1, D3.1 (K)
unnamed: Choc4.1, D4.1 (K)
unnamed: Choc5.1, D5.1 (K)
unnamed: Choc6.1, D6.1 (K)
unnamed: Choc7.1, D7.1 (K)
unnamed: Choc8.1, D8.1 (K)
unnamed: Choc9.1, D9.1 (K)

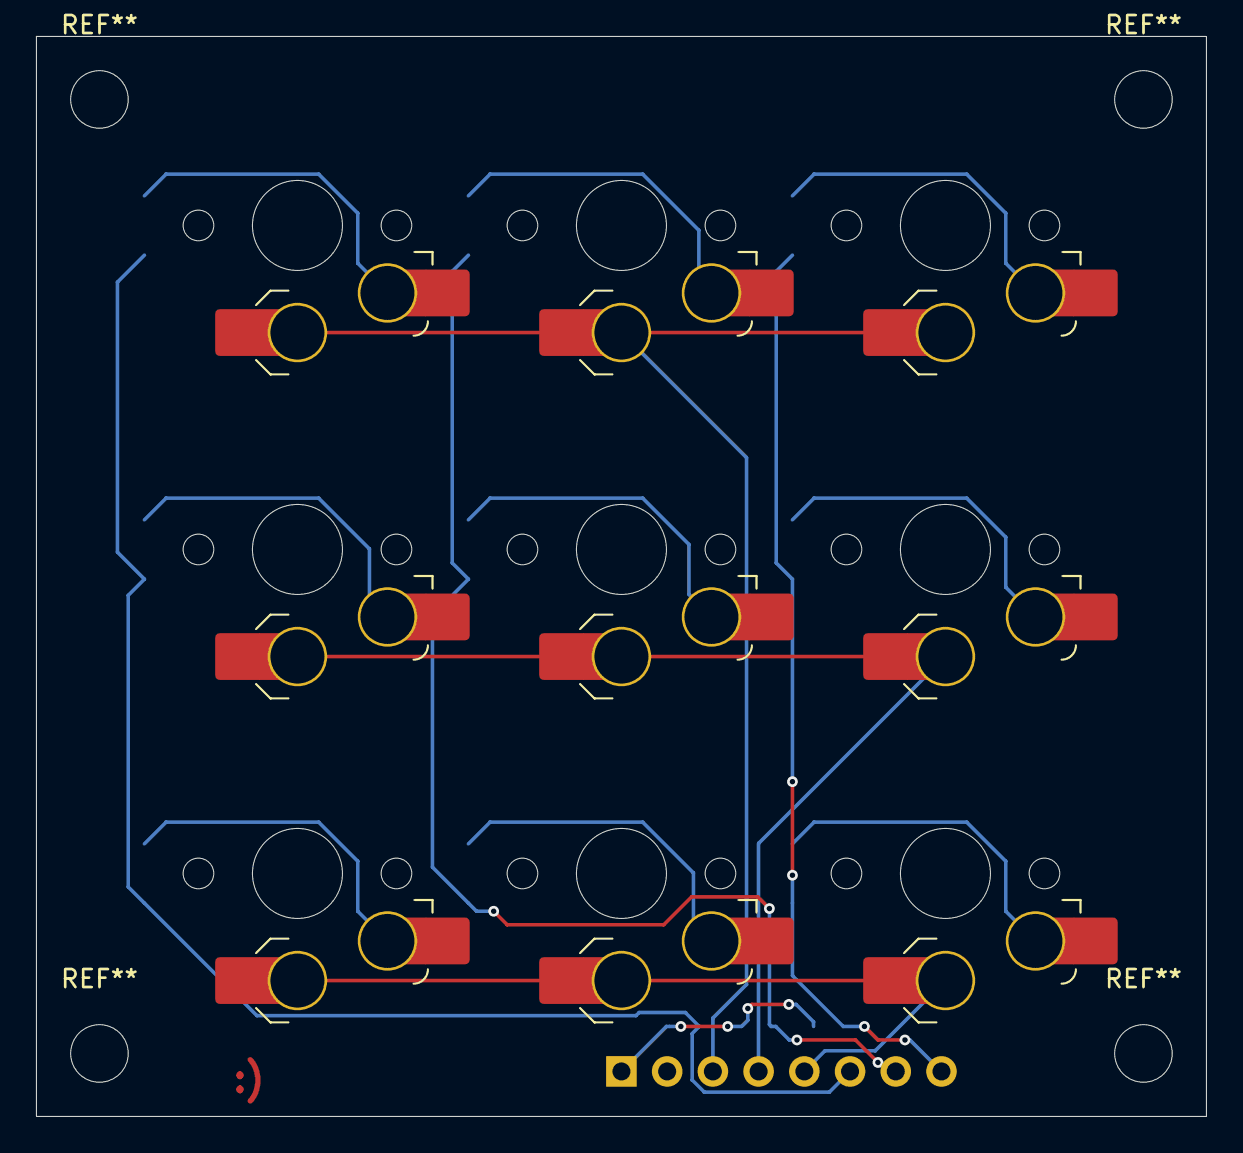
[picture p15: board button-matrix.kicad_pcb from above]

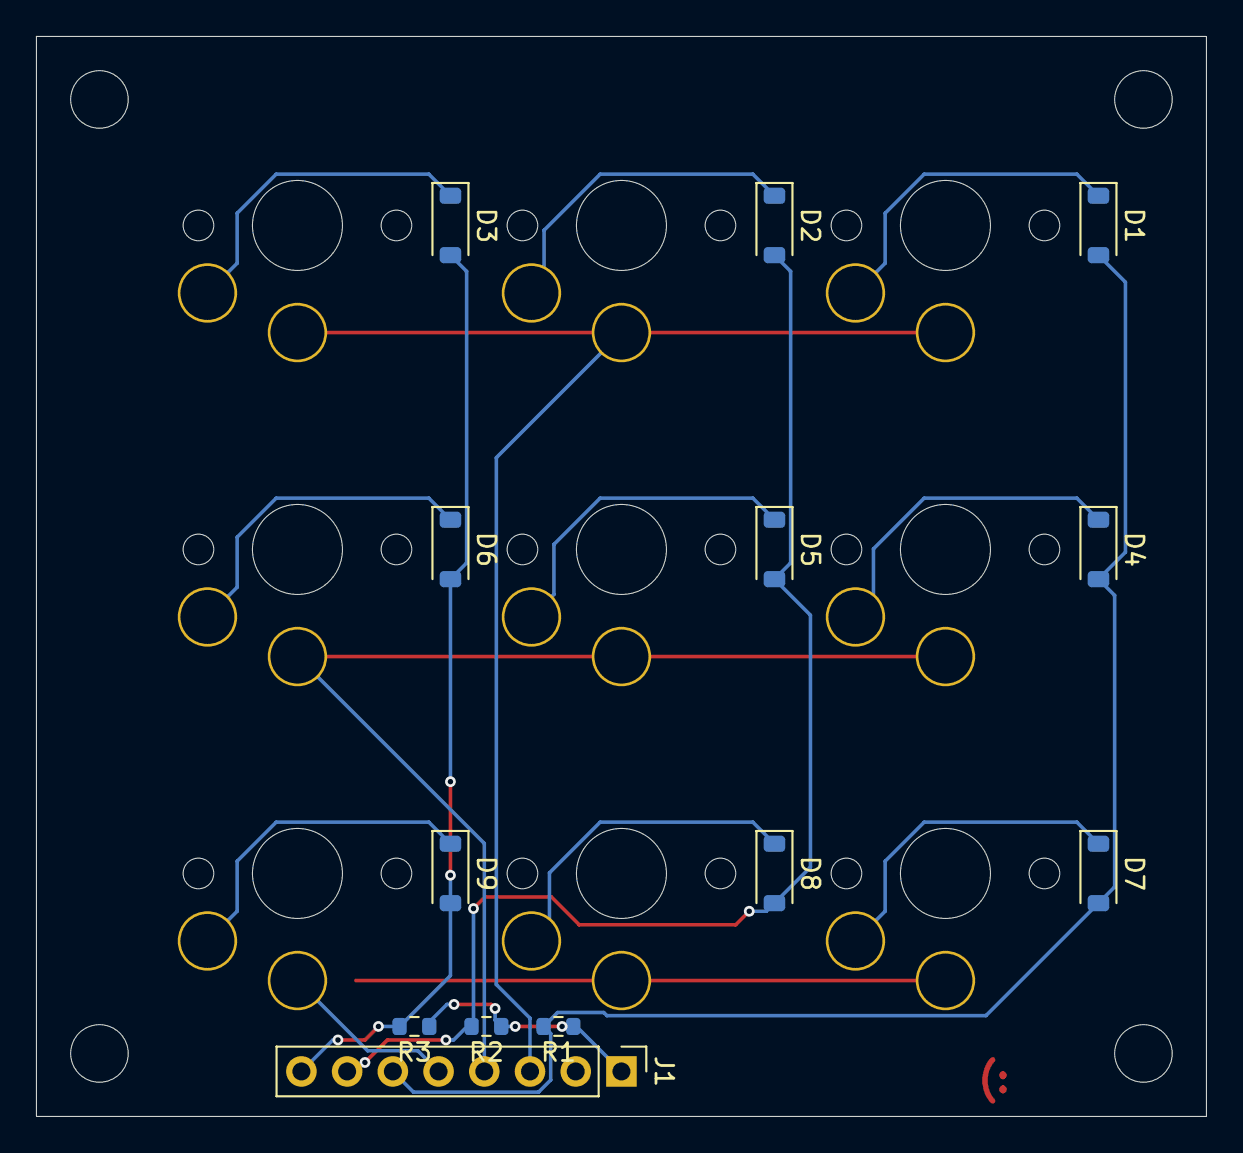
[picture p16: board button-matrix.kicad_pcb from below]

Board: 2 copper layers, 65.0 x 60.0 mm, 22 parts (13 on the bottom side), 16 nets.

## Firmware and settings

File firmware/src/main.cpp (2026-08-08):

// main.cpp -- Amigo bring-up firmware.
//
// Scope: boot, ILI9341 display, 3x3 Choc matrix, MAX98357A tone output,
// battery voltage readout, status LED heartbeat.
//
// STATUS: written against the schematic, not yet flashed to hardware.

#include <Arduino.h>
#include <TFT_eSPI.h>
#include "pins.h"
#include "keypad.h"
#include "audio.h"

TFT_eSPI tft;
Keypad keys;
Audio audio;

// Per-key tones, laid out to match the physical 3x3 grid (C major pentatonic).
static const float KEY_TONES[9] = {
    261.63f, 293.66f, 329.63f,
    392.00f, 440.00f, 523.25f,
    587.33f, 659.25f, 783.99f
};

// ---- display layout ----
static constexpr int GRID_X = 40;
static constexpr int GRID_Y = 90;
static constexpr int CELL = 50;
static constexpr int GAP = 6;

static uint32_t lastHeartbeat = 0;
static uint32_t lastBattery = 0;

void setBacklight(uint8_t level) {
    ledcWrite(BL_LEDC_CHANNEL, level); // core 2.x takes a channel, not a pin
}

float readBatteryVolts() {
    // 32 samples to knock down ADC noise. analogReadMilliVolts applies the
    // per-chip eFuse calibration, which is much better than raw counts.
    uint32_t acc = 0;
    for (int i = 0; i < 32; i++) acc += analogReadMilliVolts(PIN_BAT_SENSE);
    return (acc / 32.0f) * BAT_DIVIDER_RATIO / 1000.0f;
}

void drawCell(uint8_t r, uint8_t c, bool down) {
    const int x = GRID_X + c * (CELL + GAP);
    const int y = GRID_Y + r * (CELL + GAP);
    tft.fillRoundRect(x, y, CELL, CELL, 6, down ? TFT_CYAN : TFT_DARKGREY);
    tft.drawRoundRect(x, y, CELL, CELL, 6, TFT_WHITE);

    tft.setTextColor(down ? TFT_BLACK : TFT_WHITE);
    tft.setTextDatum(MC_DATUM);
    tft.drawNumber(r * 3 + c + 1, x + CELL / 2, y + CELL / 2, 4);
    tft.setTextDatum(TL_DATUM);
}

void drawGrid() {
    for (uint8_t r = 0; r < 3; r++)
        for (uint8_t c = 0; c < 3; c++)
            drawCell(r, c, keys.isDown(r, c));
}

void drawChrome() {
    tft.fillScreen(TFT_BLACK);
    tft.setTextColor(TFT_WHITE, TFT_BLACK);
    tft.setTextDatum(TC_DATUM);
    tft.drawString("AMIGO", tft.width() / 2, 14, 4);
    tft.setTextDatum(TL_DATUM);
    tft.drawString("bring-up", 8, 46, 2);
}

void drawBattery(float volts) {
    tft.setTextColor(TFT_LIGHTGREY, TFT_BLACK);
    tft.fillRect(0, tft.height() - 22, tft.width(), 22, TFT_BLACK);
    char buf[24];
    snprintf(buf, sizeof(buf), "BATT %.2f V", volts);
    tft.drawString(buf, 8, tft.height() - 20, 2);
}

void setup() {
    Serial.begin(115200);

    pinMode(PIN_LED_STATUS, OUTPUT);
    digitalWrite(PIN_LED_STATUS, LOW);

    // Backlight off during init so the user does not see a garbage frame.
    ledcSetup(BL_LEDC_CHANNEL, BL_LEDC_FREQ_HZ, BL_LEDC_RES_BITS);
    ledcAttachPin(PIN_LCD_BL, BL_LEDC_CHANNEL);
    setBacklight(0);

    tft.init();
    tft.setRotation(0);
    drawChrome();

    analogSetPinAttenuation(PIN_BAT_SENSE, ADC_11db); // ~0 to 3.1V usable range

    keys.begin();

    if (!audio.begin()) {
        Serial.println("[audio] I2S init failed");
        tft.setTextColor(TFT_RED, TFT_BLACK);
        tft.drawString("audio init FAILED", 8, 64, 2);
    }

    drawGrid();
    drawBattery(readBatteryVolts());

    // Fade the backlight up.
    for (int i = 0; i <= 255; i += 5) {
        setBacklight(i);
        delay(4);
    }

    if (audio.ready()) audio.bootChime();

    Serial.printf("[boot] PSRAM: %u bytes free\n", (unsigned)ESP.getFreePsram());
}

void loop() {
    audio.update(); // services the deferred amplifier shutdown

    if (keys.scan()) {
        drawGrid();
        const int k = keys.lastPressed();
        if (k >= 0 && k < 9) {
            const uint8_t r = k / 3, c = k % 3;
            if (keys.isDown(r, c)) {
                Serial.printf("[key] %d down\n", k + 1);
                audio.tone(KEY_TONES[k], 70);
            }
        }
    }

    const uint32_t now = millis();

    if (now - lastHeartbeat >= 1000) {
        lastHeartbeat = now;
        digitalWrite(PIN_LED_STATUS, !digitalRead(PIN_LED_STATUS));
    }

    if (now - lastBattery >= 5000) {
        lastBattery = now;
        drawBattery(readBatteryVolts());
    }

    delay(2);
}

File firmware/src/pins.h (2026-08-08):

// pins.h -- Amigo GPIO map, transcribed from the ESP32-S3-WROOM-1 schematic sheet.
#pragma once

// Status LED
constexpr int PIN_LED_STATUS = 2;

// Battery sense (ADC1_CH3, safe to use with WiFi active)
constexpr int PIN_BAT_SENSE = 4;

// MAX98357A I2S audio
constexpr int PIN_AUDIO_BCLK = 5;
constexpr int PIN_AUDIO_LRC = 6;
constexpr int PIN_AUDIO_DOUT = 7;

// MAX98357A SD_MODE. Not routed on rev A: this is the bodge wire from J4 pin 5
// to the IO38 castellated pad. Comment out AUDIO_SD_CONNECTED to build for a
// board without the wire, in which case the amp is always on.
#define AUDIO_SD_CONNECTED 1
constexpr int PIN_AUDIO_SD = 38;

// ILI9341 2.8" SPI display
constexpr int PIN_LCD_RST = 8;
constexpr int PIN_LCD_BL = 9;
constexpr int PIN_LCD_SCK = 10;
constexpr int PIN_LCD_MOSI = 11;
constexpr int PIN_LCD_CS = 12;
constexpr int PIN_LCD_DC = 13;

// Kailh Choc 3x3 matrix
constexpr int PIN_ROW[3] = {14, 15, 16};
constexpr int PIN_COL[3] = {17, 18, 21};

// Backlight PWM (LEDC)
constexpr int BL_LEDC_CHANNEL = 0;
constexpr int BL_LEDC_FREQ_HZ = 5000;
constexpr int BL_LEDC_RES_BITS = 8;

// Battery divider: R4 100k (BAT_SW to tap) / R5 100k (tap to GND), tap on IO4,
// filtered by C9 100nF. Ratio = (R4 + R5) / R5 = 2.0. Confirmed from schematic.
constexpr float BAT_DIVIDER_RATIO = 2.0f;

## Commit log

2026-05-06 Power section complete
    Schematic Power section
    [Amigo.kicad_sch]
2026-05-06 Wired up ESP board with all the stuff
    [Amigo.kicad_sch]
2026-05-07 Finished wiring audio amp in schematic
    [Amigo.kicad_sch]
2026-05-07 Finished wiring motor controller in schematic
    [Amigo.kicad_sch]
2026-05-07 Finished button matrix in schematic. Ready to move on to PCB
    [Amigo.kicad_sch]
2026-05-08 PCB updating and annotating
    [Amigo.csv, Amigo.kicad_pcb, Amigo.kicad_sch]
2026-05-10 Clean start in Amigo folder
    [Amigo.csv, Amigo.kicad_pcb, Amigo.kicad_sch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]
2026-05-11 Main PCB placement
    [Amigo.kicad_pcb, ButtonMatrix3x3.kicad_pcb]
2026-05-17 PCB wiring done
    [Amigo.kicad_pcb]
2026-05-19 Wiring first draft done. Will start the rewiring and try to avoid DRC errors
    [Amigo.kicad_pcb]
2026-05-19 Positioned Everything
    [Amigo.kicad_pcb]
2026-05-21 Fixed all DRC errors, Added groundpour
    [Amigo.kicad_pcb]
2026-05-21 fixed LED polarity
    [Amigo.kicad_pcb, Amigo.kicad_sch]
2026-05-21 Gerbers generated
    [Amigo-B_Cu.gbl, Amigo-B_Mask.gbs, Amigo-B_Paste.gbp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]
2026-05-21 pcb? I don't think it is updated on git
2026-05-21 Found out why there is a discrepancy with two main board files. The real one is in the Main Board folder
    [.step, Amigo.csv, Amigo.kicad_pcb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]
2026-05-23 Before removal of motors and OLED change
2026-05-24 Finished wiring up the new OLED
    [Amigo.kicad_pcb, Amigo.kicad_sch]
2026-05-25 Debugged an unconnected error and generated step and gerber
    [Amigo-B_Cu.gbl, Amigo-B_Mask.gbs, Amigo-B_Paste.gbp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]
2026-05-25 Fix another DRC error and rotated battery JST connector
    [Amigo-B_Cu.gbl, Amigo-B_Mask.gbs, Amigo-B_Paste.gbp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]
2026-05-31 idk tbh
    [Amigo.kicad_pcb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]
2026-06-22 gerber and stuff
    [Amigo-B_Cu.gbl, Amigo-B_Mask.gbs, Amigo-B_Paste.gbp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]
2026-06-28 Steps and Stls
    [OLED Mount.stl]
2026-06-29 README and Assembly Instructions
2026-07-20 Probably some ordering stuff
    [Amigo.csv, ButtonMatrix3x3.csv, bom.csv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]
2026-07-20 more organization
    [.step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]
2026-08-06 Commit before switching some files
    [.step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]
2026-08-06 Fixed everything
    [bom.csv]
2026-08-06 Added screws
    [bom.csv]
2026-08-08 Fixed the tone method to make it non blocking incase key presses are pressed during sound
    [audio.h, keypad.h, main.cpp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]
2026-10-31 added timer/alarm firmware
2026-10-31 Revert "added timer/alarm firmware"
    This reverts commit d203e0d9872c2b7619f43d73262bf9dece6f15a9.
2026-10-31 Add clock, daily alarm, and countdown timer firmware
    Reimplements the timer/alarm feature that was reverted in ae4222c, and
    fixes the audio engine it depends on.
    audio.h: the non-blocking tone refactor had left playback silent. update()
    generated samples but never called i2s_write, framesCompleted_ was never
    advanced so playing_ latched true forever, and bootChime() called tone()
    three times synchronously so each call overwrote the last. Adds the DMA
    write with a zero timeout (so a long note spreads across loop passes
    instead of stalling the key scan), correct frame accounting, phase rewind
    for samples the DMA refuses, and a small note queue so melodies and the
    repeating alert patterns work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
